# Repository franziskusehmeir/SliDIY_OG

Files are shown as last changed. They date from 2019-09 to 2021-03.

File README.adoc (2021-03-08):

== SliDIY

An affordable slider system that can be controlled with a web app via a microcontroller. It can be easily reconstructed at home with the help of a manual.

==== News
This repo has moved to https://github.com/franziskusehmeir/SliDIY

==== Authors

* *Tea Leon* - https://github.com/tealeon[TeaLeon]
* *Ehmeir Franziskus* -
https://github.com/franziskusehmeir[FranziskusEhmeir]

See also the list of
https://github.com/franziskusehmeir/SliDIY/contributors[contributors]
who participated in this project.

=== GH Page

https://franziskusehmeir.github.io/SliDIY_OG/

=== Youtrack

https://vm81.htl-leonding.ac.at/agiles/99-166/current

=== How to run

1. download & extract the latest *release.zip*

2. run the *configure.sh* 

  chmod +x script-name-here.sh
  ./configure.sh

3. enable spi on the rpi +
* *Menu* > *Preferences* > *Raspberry Pi Configuration* > *Interfaces* Tab
* set SPI to “Enabled”

4. reboot the rpi
  
5. run app

  python slidiy.py

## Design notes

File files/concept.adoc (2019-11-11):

== Concept for a motorized camera-slider

=== Introduction / Environment

A slider is a ``rail system'' that allows smooth camera movements.
Motorized versions are very expensive and non-motorized systems again
create a risk of shaky footage or irregular camera movements.

=== Starting position / current situation / analysis

==== Initial situation

The higher technical college in Leonding is a medium-sized school in the
central region of Upper Austria. One of the four departments is IT media
technology. There, media production is a clear focus of the training.

==== Current situation

In video productions, sliders have been used for many years to make
stable horizontal and vertical shots possible. These can be motorized or
not.

=== Target system / target proposals

==== Aims

The development of an affordable slider system that can be controlled
with an app via a microcontroller.

==== Target groups

People that are interested in Film, but have a very small budget.

==== Conflicting goals

Easy to use, portable system Wiring, 3D printing, fragility

=== Implementations

==== First technical realization

ESP32 + Stepper Motor + C++ Code

==== Second technical realization

ESP8266 + stepper motor + necessary hardware for connection (stepper
motor driver h-bridge) Blynk app

=== Sources

==== Lync App

https://youtu.be/dKzCZhnLUyc

==== Joystick change speed

https://youtu.be/dQuTgngoFPQ

==== Joystick Tuto

https://youtu.be/gudmACeUyVc

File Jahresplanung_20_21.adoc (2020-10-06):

== SliDIY - Jahresausblick 20/21

=== Allgemeines
Ein erschwingliches Slider-System, das mit einer Web-App über einen Microcontroller gesteuert werden kann. Es kann zu Hause mit Hilfe eines Handbuchs leicht rekonstruiert werden.

=== Status Quo
SliDIY kann einfache Bewegungen und Presets durchführen. Er benötigt aber drei Steckdosen. Es ist noch kein Case vorhanden. Verschiedene Geschwindigkeiten sind noch nicht fehlerfrei möglich. Authentifizierung läuft noch über cnc.js.

=== Meilensteine

- Hardware Änderung auf US & Usablility Verbesserungen | 01.12.20
* [ ] Ultraschallsensoren einbauen
* [ ] Kabelmanagement
** Kabel zusammenfassen
** Kabel sortieren
* [ ] Akku
** Verschiedene Möglichkeiten analysieren
** Akku/Powerbank einbauen

* [ ] Neuer Motor
* [ ] 3D Modell Case
** 3D Modell entwerfen
** 3D Modell drucken
** Case einbauen

- Software Änderung: Clean up & Features | 01.02.21
* [ ] Positionsermittlung USS
** Werte lesen vom Ultraschallsensor
** Position der Kamera berechnen mit zwei gemessenen Entfernungen

* [ ] Endabschaltung USS
** Motor aus sobald eine minimale Entfernung erreicht ist

* [ ] Code Clean Up

* [ ] Emergency Ende UI
** Stop Button in der UI hinzufügen

* [ ] Authentifizierung
** cnc.js analysieren
** grbl auth implementieren

//* [ ] Speed:Percentage

- Dokumentation & Anleitung | 01.03.21
* [ ] Genaue Domumentation
* [ ] Detaillierte Anleitung

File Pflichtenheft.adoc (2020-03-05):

== Pflichtenheft für motorisierten Kamera-Slider

_Tea Leon & Ehmeir Franziskus_

=== Ausgangssituation

Videos werden auf verschiedenen Geräten aufgenommen, mit Handys bis zu professionellen Filmkameras.

=== Ist-Situation

In semi-professionellen Filmproduktionen ist es oft wichtig, eine 
ruhige Kamerafahrt zu erstellen.

In Videoproduktionen werden seit vielen Jahren Slider verwendet um
stabile horizontale und vertikale Aufnahmen zu machen. Diese können
motorisiert sein oder nicht.

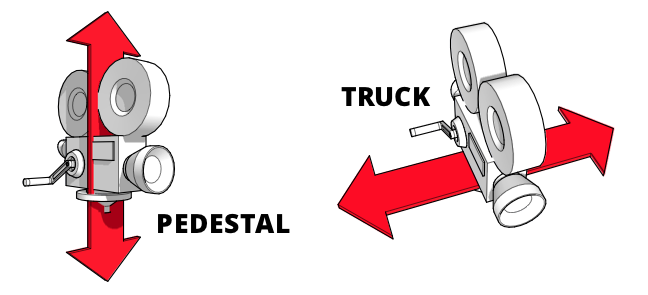
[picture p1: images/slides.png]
Movements


=== Problem

Wenn man versucht per Hand bewegte Aufnahmen zu machen, endet man meist mit verwackeltem oder sogar unbrauchbarem Videomaterial. Weiters werden die meisten Zeitrafferaufnahmen langweilig, da sie keine Bewegung beinhalten. Die Lösung dieser Probleme wären motorisierte Slidersysteme. Motorisierte Slider sind sehr teuer und meist unerschwinglich für den durchschnittlichen Anwender. Billige Alternativen sind unmotorisiert und dadurch entsteht wieder eine Verwackelungsgefahr bzw. unregelmäßige Bewegungsgeschwindigkeiten.

=== Aufgabenstellung

Es ist ein erschwingliches Slider-System zu entwickeln, das sowohl horizontale als auch schräge Kamerabewegungen durchführen kann. Die montierte Kamera wird einen vorgegeben Streckenabschnitt in einer ebenso vorgegebenen Zeit zurücklegen. Somit können z.B. auch Zeitrafferaufnahmen erstellt werden. Der Motor des Sliders wird über einen Micro-Controller angesprochen werden. Später wird das System mit einer App gesteuert werden können. Außerdem ist eine Anleitung zu erstellen, damit Leute das Slider-System nachbauen können.

=== Ziele

Filmbegeisterten Menschen soll es ermöglicht werden, mithilfe der Dokumentation selbst einen Kamera-Slider nachzubauen und ihn in Betrieb zu nehmen. Somit können sie qualitativ hochwertige Aufnahmen erstellen, die frei von Verwacklungen und Geschwindigkeitsnderungen sind.

=== User Storys nach Scrum

Als Content-Creator möchte ich reibungslose, horizontale wie auch
vertikale Kamerabewegungen anwenden.

Als Naturfotograf möchte ich bewegte Zeitraffer erstellen.

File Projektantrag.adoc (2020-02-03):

== Projektantrag

_Tea Leon & Ehmeir Franziskus_

=== Ausgangssituation

In Videoproduktionen werden seit vielen Jahren Slider verwendet um
stabile horizontale und vertikale Aufnahmen zu machen. Diese können
motorisiert sein oder nicht.

=== Problemstellung

Wenn man versucht per Hand bewegte Aufnahmen zu machen, endet man meist mit verwackeltem oder sogar unbrauchbarem Videomaterial.
Weiters werden die meisten Zeitrafferaufnahmen langweilig, da sie keine Bewegung beinhalten. Die Lösung dieser Probleme wären
motorisierte Slidersysteme. Motorisierte Slider sind sehr teuer und meist unerschwinglich für den durchschnittlichen Anwender.
Billige Alternativen sind unmotorisiert und dadurch entsteht wieder eine Verwackslungsgefahr bzw. unregelmäßige 
Bewegungsgeschwindigkeiten.

=== Aufgabenstellung

Es ist ein erschwingliches Slider-System zu entwickeln, das sowohl horizontale als auch schräge Kamerabewegungen durchführen 
kann. Die montierte Kamera wird einen vorgegeben Streckenabschnitt in einer ebenso vorgegebenen Zeit zurücklegen. 
Somit können z.B. auch Zeitrafferaufnahmen erstellt werden. Der Motor des Sliders wird über einen Micro-Controller 
angesprochen werden. Später wird das System mit einer App gesteuert werden können.

=== Anwendungsfälle

Das System ermöglicht ruhige Kamerabewegungen und bewegte Zeitrafferaufnahmen. Es eignet sich für Personen die für geringes
Geld diese Kamerabewegungen verwenden möchten. Weiters eignet es sich ach für Lehrkräfte, die ihren Schülern einen Einblick in
profesionelles Equipment geben möchten.

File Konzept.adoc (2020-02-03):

== Konzept für motorisierten Slider

_Tea Leon & Ehmeir Franziskus_

=== Einleitung / Rahmenbedingung

Ein Slider ist ein „Schienensystem“ das scheinbar schwebende
Kamerafahrten ermöglicht. Motorisierte Ausführungen sind sehr teuer und
bei unmotorisierten Systemen entsteht wieder eine Verwackslungsgefahr.

=== Ausgangslage / Ist-Situation / Analyse

==== Ausgangssituation

Die HTL Leonding ist eine mittelgroße Schule im Zentralraum OÖ. Einer der vier Ausbildungsrichtungen ist IT-Medientechnik. Dort bildet die Medienproduktion einen der Schwerpunkte der Ausbildung.

==== Ist-Situation

In Videoproduktionen werden seit vielen Jahren Slider verwendet, um
stabile horizontale und vertikale Aufnahmen zu machen. Diese können
motorisiert sein oder nicht.

=== Zielsystem / Sollvorschläge

==== Ziele

Mehr filmbegeisterten Menschen soll die Möglichkeit zum Besitz eines günstigen, motorisierten Slider-Systems geschaffen werden.
Es soll eine App zur praktischeren und bequemeren Verwendung des Systems entwickelt werden.

==== Zielgruppen

Filminteressierte Personen mit sehr kleinem Budget.
Lehrkräfte, die ihren Schülern professionelles Equipment zeigen möchten.
Fotografen, die bewegte Zeitrafferaufnahmen erstellen möchten. 

==== Zielkonflikte

Leicht anwendbares, portables System 
Verkabelungen, 3D Druck, Zerbrechlichkeit

=== Realisierung

Arduino UNO + CNC Shield + Stepper Motor

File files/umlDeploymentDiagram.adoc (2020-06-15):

@startuml

skinparam ArrowColor black
skinparam handwritten true
skinparam borderColor black
skinparam backgroundColor transparent
skinparam nodeShadowing false
skinparam nodeBackgroundColor transparent
skinparam artifactShadowing false
skinparam artifactBackgroundColor transparent
skinparam componentShadowing false
skinparam componentBackgroundColor transparent
skinparam componentBorderColor black

@startuml

node raspberryPi{
 artifact nodejsApp{
    artifact UI
    artifact Logic
 }
}

node arduino{
 artifact grbl
 component CNCShield
}

node steppermotor{

}

Logic == grbl : <<serial>>
CNCShield == steppermotor : <<i2c>>

@enduml
@enduml

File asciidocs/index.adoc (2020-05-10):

= SliDIY

== Pflichtenheft "Was mache ich"

=== Ausgangssituation

Videos werden auf verschiedenen Geräten aufgenommen, mit Handys bis zu professionellen Filmkameras.

=== Ist-Situation

In semi-professionellen Filmproduktionen ist es oft wichtig, eine 
ruhige Kamerafahrt zu erstellen.

In Videoproduktionen werden seit vielen Jahren Slider verwendet um
stabile horizontale und vertikale Aufnahmen zu machen. Diese können
motorisiert sein oder nicht.

Movements

=== Problemstellung

Wenn man versucht per Hand bewegte Aufnahmen zu machen, endet man meist mit verwackeltem oder sogar unbrauchbarem Videomaterial. Weiters werden die meisten Zeitrafferaufnahmen langweilig, da sie keine Bewegung beinhalten. Die Lösung dieser Probleme wären motorisierte Slidersysteme. Motorisierte Slider sind sehr teuer und meist unerschwinglich für den durchschnittlichen Anwender. Billige Alternativen sind unmotorisiert und dadurch entsteht wieder eine Verwackelungsgefahr bzw. unregelmäßige Bewegungsgeschwindigkeiten.

=== Aufgabenstellung

Es ist ein erschwingliches Slider-System zu entwickeln, das sowohl horizontale als auch schräge Kamerabewegungen durchführen kann. Die montierte Kamera wird einen vorgegeben Streckenabschnitt in einer ebenso vorgegebenen Zeit zurücklegen. Somit können z.B. auch Zeitrafferaufnahmen erstellt werden. Der Motor des Sliders wird über einen Micro-Controller angesprochen werden. Später wird das System mit einer App gesteuert werden können. Außerdem ist eine Anleitung zu erstellen, damit Leute das Slider-System nachbauen können.

==== Funktionale Anforderungen

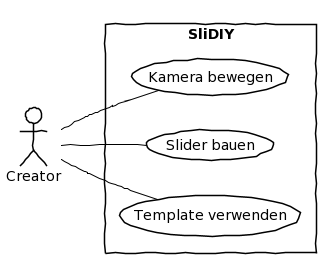
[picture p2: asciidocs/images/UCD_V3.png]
usecasediagram


==== Nichtfunktionale Anforderungen

Die Oberfläche gewährleistet eine gute Übersicht und eine leichte Bedienung. +
Die Komponenten des Systems sind erschwinglich. +
Es wird eine simple Anleitung zum Nachbau zur Verfügung gestellt.

=== Ziele

Filmbegeisterten Menschen soll es ermöglicht werden, mithilfe der Dokumentation selbst einen Kamera-Slider nachzubauen und ihn in Betrieb zu nehmen. Somit können sie qualitativ hochwertige Aufnahmen erstellen, die frei von Verwacklungen und Geschwindigkeitsnderungen sind.

=== User Storys nach Scrum

Als Content-Creator möchte ich reibungslose, horizontale wie auch
vertikale Kamerabewegungen anwenden.

Als Naturfotograf möchte ich bewegte Zeitraffer erstellen.

== Entwurf "Wie mache ich es"

=== System Architecture (Hardware)

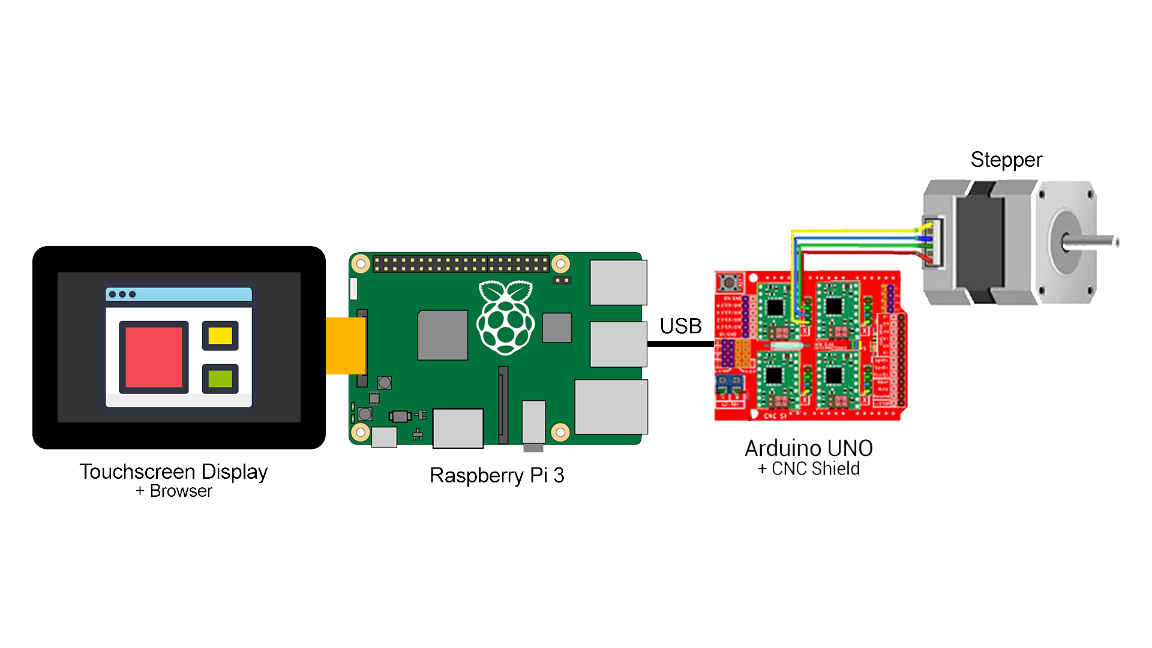
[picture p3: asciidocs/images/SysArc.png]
systemarchitecture


=== Deployment Diagram

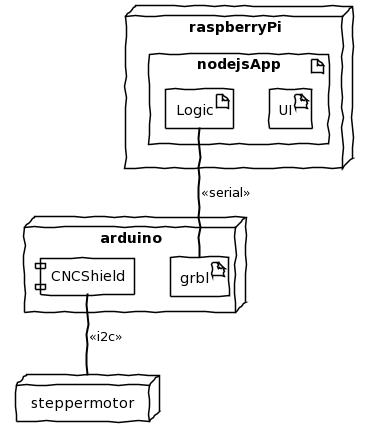
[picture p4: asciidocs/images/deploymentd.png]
deployment_diagram


=== Use Case Diagram

usecasediagram

=== Youtrack Diagram Epic

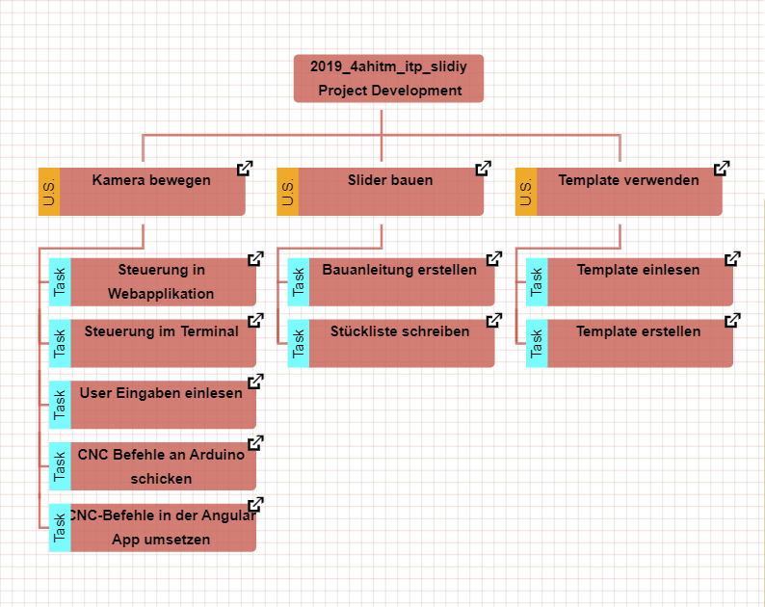
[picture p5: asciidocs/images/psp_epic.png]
pspepic


=== Youtrack Diagram Sprints
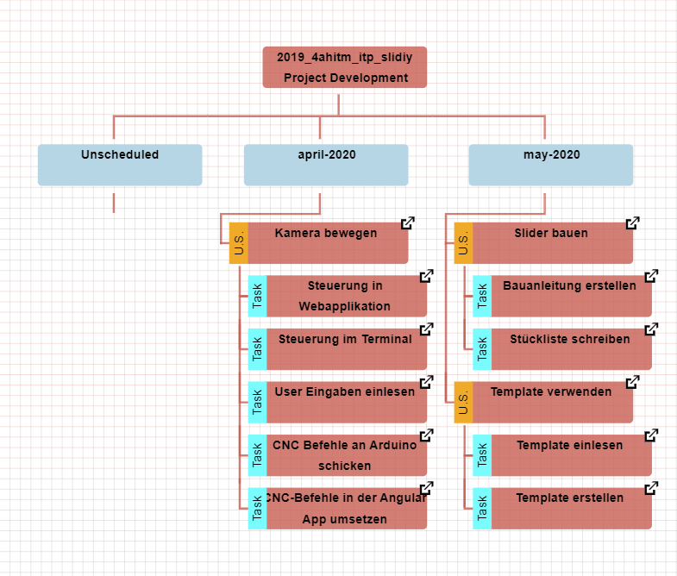
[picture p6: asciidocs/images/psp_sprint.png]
pspsprints


== Projekthandbuch "Organisatorische Rahmenbedigungen"

=== Gantt Diagram
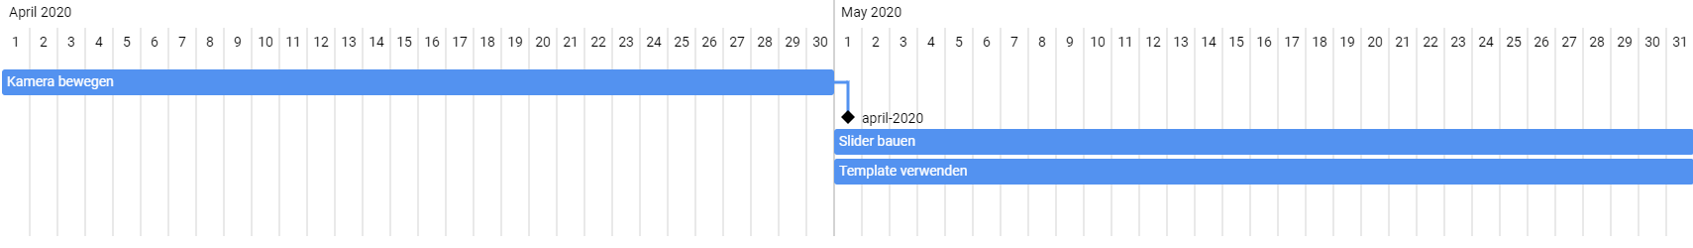
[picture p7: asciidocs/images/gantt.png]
gantt


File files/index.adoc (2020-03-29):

== Pflichtenheft "Was mache ich"

=== Ausgangssituation

Videos werden auf verschiedenen Geräten aufgenommen, mit Handys bis zu professionellen Filmkameras.

=== Ist-Situation

In semi-professionellen Filmproduktionen ist es oft wichtig, eine 
ruhige Kamerafahrt zu erstellen.

In Videoproduktionen werden seit vielen Jahren Slider verwendet um
stabile horizontale und vertikale Aufnahmen zu machen. Diese können
motorisiert sein oder nicht.

Movements

=== Problemstellung

Wenn man versucht per Hand bewegte Aufnahmen zu machen, endet man meist mit verwackeltem oder sogar unbrauchbarem Videomaterial. Weiters werden die meisten Zeitrafferaufnahmen langweilig, da sie keine Bewegung beinhalten. Die Lösung dieser Probleme wären motorisierte Slidersysteme. Motorisierte Slider sind sehr teuer und meist unerschwinglich für den durchschnittlichen Anwender. Billige Alternativen sind unmotorisiert und dadurch entsteht wieder eine Verwackelungsgefahr bzw. unregelmäßige Bewegungsgeschwindigkeiten.

=== Aufgabenstellung

Es ist ein erschwingliches Slider-System zu entwickeln, das sowohl horizontale als auch schräge Kamerabewegungen durchführen kann. Die montierte Kamera wird einen vorgegeben Streckenabschnitt in einer ebenso vorgegebenen Zeit zurücklegen. Somit können z.B. auch Zeitrafferaufnahmen erstellt werden. Der Motor des Sliders wird über einen Micro-Controller angesprochen werden. Später wird das System mit einer App gesteuert werden können. Außerdem ist eine Anleitung zu erstellen, damit Leute das Slider-System nachbauen können.

==== Funktionale Anforderungen

usecasediagram

==== Nichtfunktionale Anforderungen

Die Oberfläche gewährleistet eine gute Übersicht und eine leichte Bedienung. +
Die Komponenten des Systems sind erschwinglich. +
Es wird eine simple Anleitung zum Nachbau zur Verfügung gestellt.

=== Ziele

Filmbegeisterten Menschen soll es ermöglicht werden, mithilfe der Dokumentation selbst einen Kamera-Slider nachzubauen und ihn in Betrieb zu nehmen. Somit können sie qualitativ hochwertige Aufnahmen erstellen, die frei von Verwacklungen und Geschwindigkeitsnderungen sind.

=== User Storys nach Scrum

Als Content-Creator möchte ich reibungslose, horizontale wie auch
vertikale Kamerabewegungen anwenden.

Als Naturfotograf möchte ich bewegte Zeitraffer erstellen.

== Entwurf "Wie mache ich es"

=== System Architecture (Hardware)

systemarchitecture

=== Deployment Diagram

deployment_diagram

=== Use Case Diagram

usecasediagram

=== Youtrack Diagram Epic

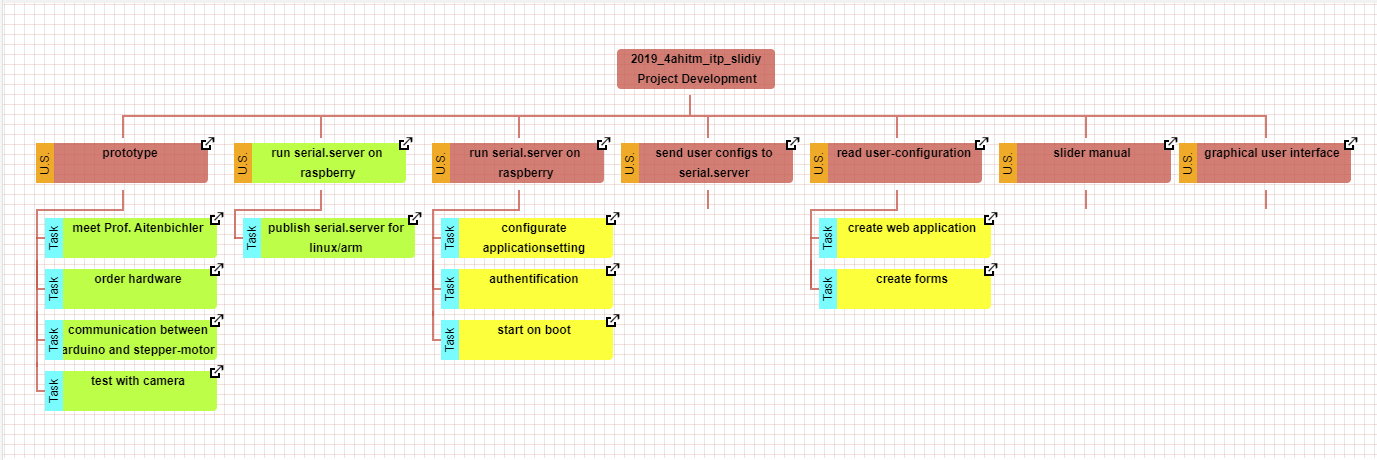
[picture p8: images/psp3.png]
pspepic


=== Youtrack Diagram Sprints
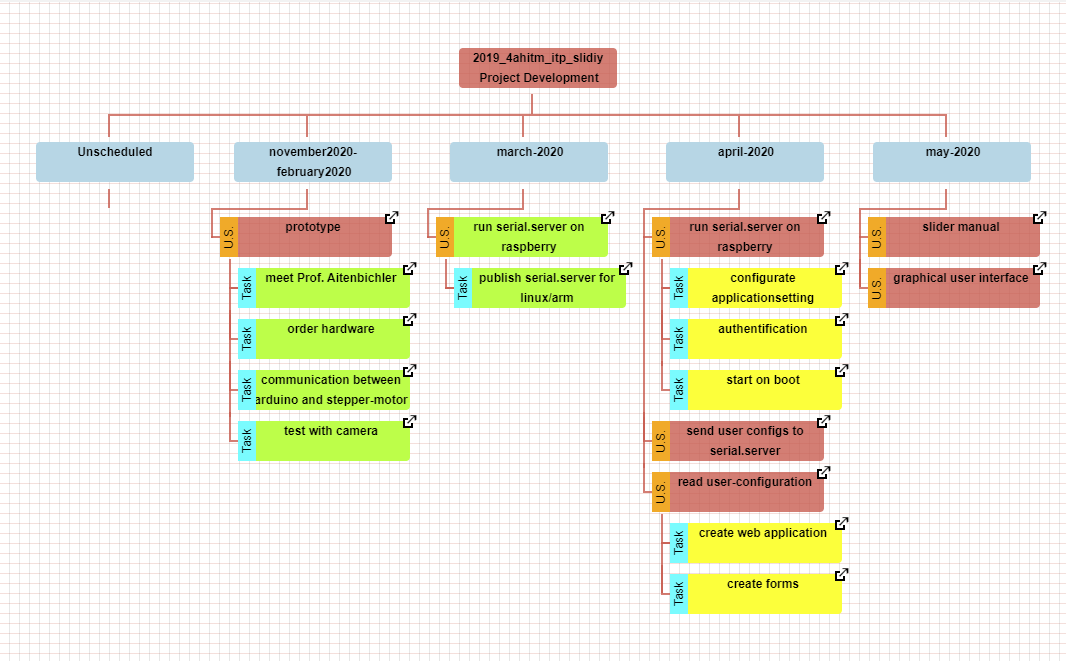
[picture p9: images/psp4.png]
pspsprints


== Projekthandbuch "Organisatorische Rahmenbedigungen"

=== Gantt
gantt

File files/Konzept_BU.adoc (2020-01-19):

== Konzept für motorisierten Slider

=== Einleitung / Rahmenbedingung

Ein Slider ist ein „Schienensystem“ das scheinbar schwebende
Kamerafahrten ermöglicht. Motorisierte Ausführungen sind sehr teuer und
bei unmotorisierten Systemen entsteht wieder eine Verwackslungsgefahr.

=== Ausgangslage / Ist-Situation / Analyse

==== Ausgangssituation

Die HTL Leonding ist eine mittelgroße Schule im Zentralraum OÖ. Einer
der vier Ausbildungsrichtungen ist IT-Medientechnik. Dort bildet die
Medienproduktion einen klaren Schwerpunkt der Ausbildung.

==== Ist-Situation

In Videoproduktionen werden seit vielen Jahren Slider verwendet, um
stabile horizontale und vertikale Aufnahmen zu machen. Diese können
motorisiert sein oder nicht.

=== Zielsystem / Sollvorschläge

==== Ziele

Es ist ein erschwingliches Slider-System zu entwickeln, dass über einen
Micro-Controller mit einer App gesteuert werden kann.

==== Zielgruppen

Filminteressierte Personen mit sehr kleinem Budget.

==== Zielkonflikte

Leicht anwendbares, portables System Verkabelungen, 3D Druck,
Zerbrechlichkeit

=== Realisierungen

==== Realisierung 1

ESP8266 + Stepper Motor + Nötige Hardware zur Verbindung (stepper motor
driver h-bridge) Blynk-App

==== Realisierung 2

ESP32 + Stepper Motor + C++ Code

=== Qellen

==== Lync App

https://youtu.be/dKzCZhnLUyc

==== Joystick change speed

https://youtu.be/dQuTgngoFPQ

==== Joystick Tuto

https://youtu.be/gudmACeUyVc

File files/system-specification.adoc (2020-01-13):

== Pflichtenheft für motorisierten Kamera-Slider

_Ehmeir Franziskus & Tea Leon_

=== Ausgangssituation

Die HTL Leonding ist eine mittelgroße Schule im Zentralraum OÖ. Einer der vier Ausbildungsrichtungen ist IT-Medientechnik. Dort bildet die Medienproduktion einen klaren Schwerpunkt der Ausbildung.

=== Ist-Situation

Horizontale und vertikale Videoaufnahmen sind händisch oft verwackelt. Um stabile Aufnahmen zu erreichen werden teure Werkzeuge benötigt.

Movements

=== Problem

Motorisierte Slider sind sehr teuer und meist unerschwinglich für den durchschnittlichen Anwender. Billige Alternativen sind unmotorisiert und dadurch entsteht wieder eine Verwackslungsgefahr bzw. unregelmäßige Bewegungsgeschwindigkeiten.

=== Aufgabenstellung
Es ist ein erschwingliches Slider-System zu entwickeln, dass über einen Micro-Controller mit einer App gesteuert werden kann.

=== Ziele

Mehr filmbegeisterten Menschen soll die Möglichkeit zum Besitz eines günstigen, motorisierten Slider-Systems geschaffen werden.

=== User Storys nach Scrum

* Als Content-Creator möchte ich reibungslose, horizontale wie auch vertikale Kamerabewegungen anwenden.
* Als Naturfotograf möchte ich bewegte Zeitraffer erstellen.
* Als Lehrer möchte ich meinen Schülern die Möglichkeit bieten mit professionellem Equipment zu arbeiten.

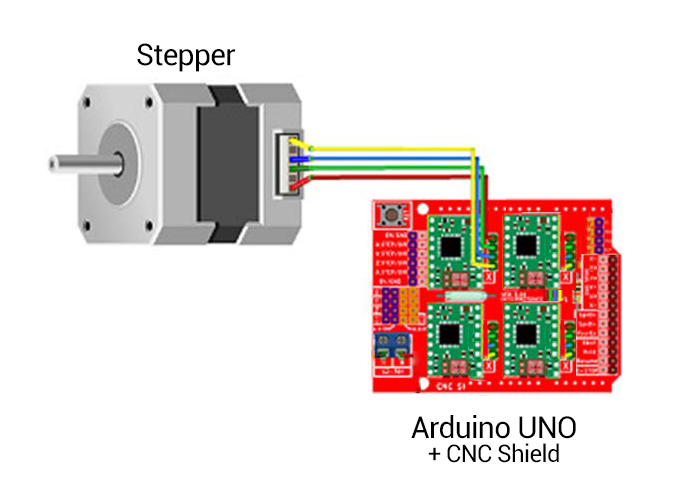
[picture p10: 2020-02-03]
docs/images/systemarchitecture.jpg

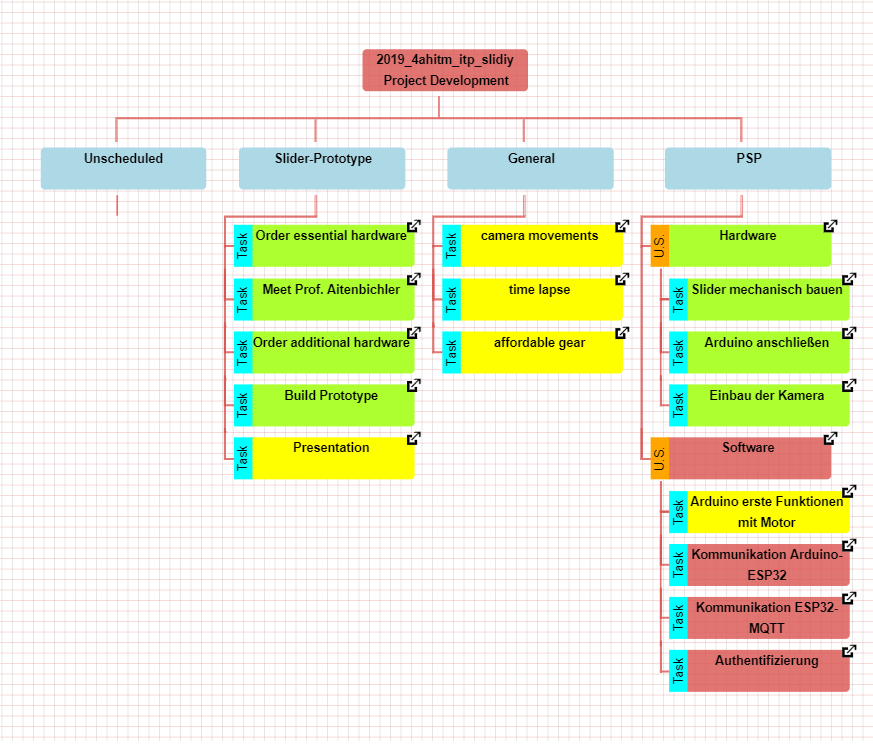
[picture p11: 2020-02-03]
docs/images/psp.PNG

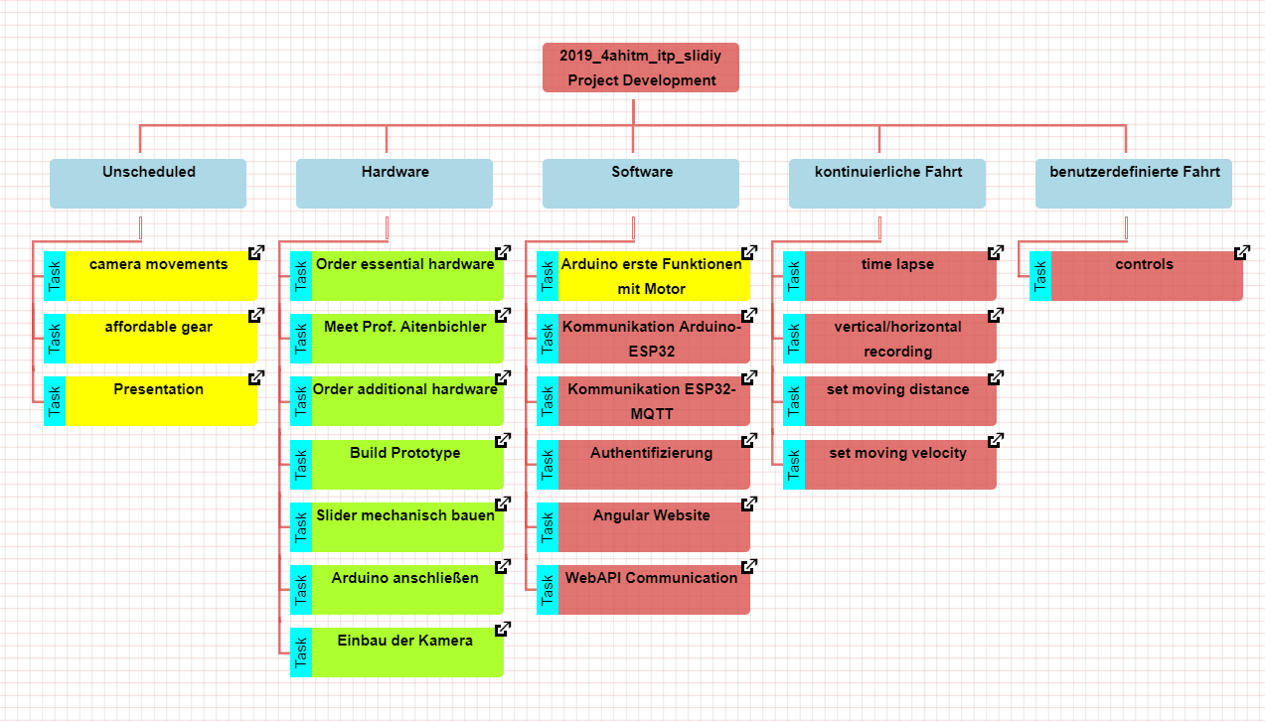
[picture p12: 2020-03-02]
docs/images/psp_new.PNG

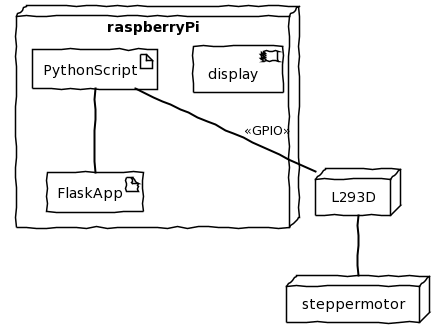
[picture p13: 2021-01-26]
docs/images/deploymentd.png

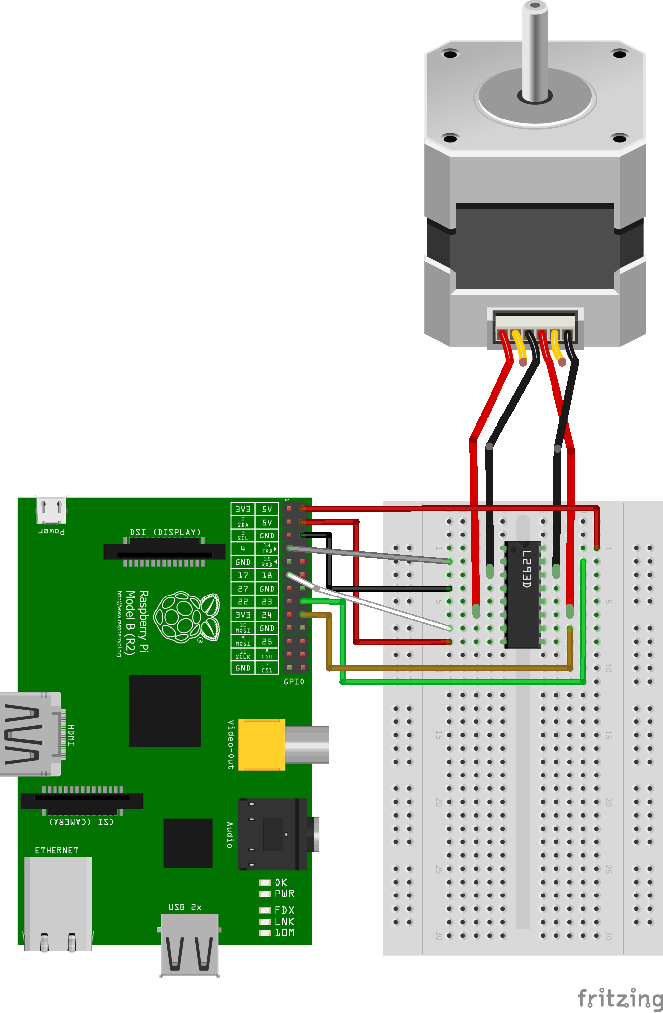
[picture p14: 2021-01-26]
docs/images/SysArcNew.png

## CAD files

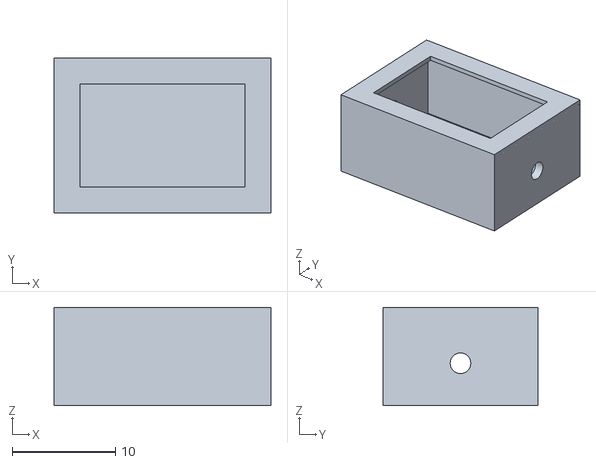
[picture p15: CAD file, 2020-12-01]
files/3d_case.stl
21.0 x 15.0 x 9.50

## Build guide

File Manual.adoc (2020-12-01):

= How to build a motorized slider
Doc Writer <doc.writer@asciidoctor.org>
v0.1.0, 2020-08-01
:toc: left

== Build your own slider

With the help of SliDIY it is made possible to easily build your own motorized slider.
SliDIY is a web application which controls the movement of your slider.

Aufbau

=== Hardware list

camera-slider: +
https://www.amazon.de/gp/product/B06Y46H989/

stepper motor: +
https://www.amazon.de/gp/product/B00PNEQKC0/

Arduino Uno with CNC-Shield V3.0 (with USB-cable and drivers) +

touchscreen display (optional): +
https://www.amazon.de/Raspberry-Pi-7-Inch-Screen-Display/dp/B014WKCFR4 +

timing belt with accessories: +
https://www.amazon.de/gp/product/B07JGXG7S2/ref=ppx_yo_dt_b_asin_title_o00_s00?ie=UTF8&psc=1

=== Software installation

Download the Raspbian Buster Lite Image: +
https://www.raspberrypi.org/downloads/raspbian/

write the image with help of the Raspberry Pi Imager onto the sd-card: +
https://www.raspberrypi.org/downloads/

first follow the instruction of the Raspberry Pi

then unlock ssh in the raspi-config

``raspi-config`` +
In this menu change to the tab "Interfacing Options" and enable the option "SSH". After this you need to reboot your
your Raspberry Pi.

install CNCJS on the Raspberry: +

``
sudo apt-get update
``

``
sudo apt-get upgrade -y
``

``
sudo apt-get dist-upgrade -y
``

``
sudo apt-get install -y build-essential git
``

``
sudo apt-get install -y htop iotop nmon lsof screen
``

``
sudo reboot
``

``
curl -sL https://deb.nodesource.com/setup_8.x | sudo -E bash -
``

``
sudo apt install -y nodejs build-essential
``

``
sudo apt-get install -y npm
``

``
sudo npm install -g npm@latest
``

``
sudo npm install -g cncjs@latest --unsafe-perm
``

``
cncjs
``

you can now check under localhost:8000 if the installation was successful

reboot Raspberry Pi  +
``
sudo reboot
``

=== 3D-Case

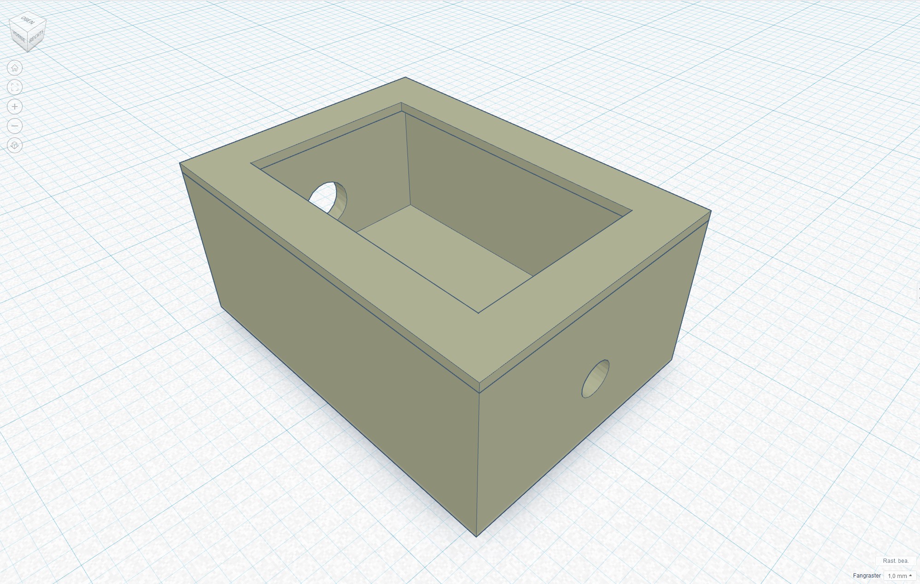
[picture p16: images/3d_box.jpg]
3d-case


We used https://www.tinkercad.com/[Tinkercad] for modeling our 3D-Case since it is made for people who have
never touched a 3D-modeling software like Blender or Cinema4D. Tinkercad is a simple web-based modeling-tool.
You have to export your 3d-model as a STL-file for the 3d-printing.

other option to Tinkercad:

* Blender
* Cinema4D
* Meshlab
* Meshmixer
* Microsoft 3D Builder

There are no strict rules on how to design your case, so model it the way you want or download our model!

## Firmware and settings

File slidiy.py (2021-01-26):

from flask import Flask, render_template_string, request 
import RPi.GPIO as GPIO
import time
 
GPIO.setmode(GPIO.BCM)
GPIO.setwarnings(False)
coil_A_2_pin = 4 # A\ gruen-weiss
coil_B_1_pin = 17 # B rot-lila
coil_A_1_pin = 23 # A schwarz-schwarz
coil_B_2_pin = 24 # B\ blau-grau

# anpassen, falls andere Sequenz
# eine ganze Sequenz entspricht 0.08cm
StepCount = 4
Seq = list(range(0, StepCount))
Seq[0] = [1,0,1,0]
Seq[1] = [0,1,1,0]
Seq[2] = [0,1,0,1]
Seq[3] = [1,0,0,1]

GPIO.setup(coil_A_1_pin, GPIO.OUT)
GPIO.setup(coil_A_2_pin, GPIO.OUT)
GPIO.setup(coil_B_1_pin, GPIO.OUT)
GPIO.setup(coil_B_2_pin, GPIO.OUT)

# Slider-Laenge in cm
sliderLength = 55

# Anzahl an Steps fuer eine ganze Kamerafahrt
completeSteps = sliderLength/0.08

app = Flask(__name__)
 
#HTML 

TPL = '''

<html>

    <head>
        <title>SliDIY</title>
        <link rel="stylesheet" href="{{ url_for('static', filename='styles/style.css') }}">
        
    </head>

    <body>

    <div>

    <h2>SliDIY</h2>

        <form method="POST" action="run">
            
            <p>Distance: <span id="value"></span>cm</p>
            <input type="range" id="distance" name="distance" min="-55" max="55" value="0"><br>
            
            <label for="time">Time in s:</label><br>
            <input type="number" id="time" name="time" min=1 value=5><br>
            
            <br>
            <input type="submit" value="run" />

        </form>
    </div>
    
        <script>
            var slider = document.getElementById("distance");
            var output = document.getElementById("value");

            output.innerHTML = slider.value;

            slider.oninput = function() {
                output.innerHTML = this.value;
            }
        </script>
        
    </body>

</html>

'''

# Zustand der Pins setzen
def setStep(w1, w2, w3, w4):
    GPIO.output(coil_A_1_pin, w1)
    GPIO.output(coil_A_2_pin, w2)
    GPIO.output(coil_B_1_pin, w3)
    GPIO.output(coil_B_2_pin, w4)
 
def acceleration(delay, steps, currentStep):
    acc_time=0.01-delay
    acc_steps=steps/9
    acc_delay=acc_time/acc_steps
    if(delay<0.01 and currentStep < acc_steps):
        time.sleep(delay+(acc_delay*(acc_steps-currentStep)))
    elif(delay<0.01 and currentStep > steps-acc_steps):
        time.sleep(delay+(acc_delay*(acc_steps-(steps-currentStep))))
    else:
        time.sleep(delay)
        
    
 
def forward(delay, steps):
    for i in range(steps):
        for j in range(StepCount):
            setStep(Seq[j][0], Seq[j][1], Seq[j][2], Seq[j][3])
            acceleration(delay, steps, i)
 
def backwards(delay, steps):
    for i in range(steps):
        for j in reversed(range(StepCount)):
            setStep(Seq[j][0], Seq[j][1], Seq[j][2], Seq[j][3])
            acceleration(delay, steps, i)
            
 

@app.route("/")

def home():

    setStep(0,0,0,0)

    return render_template_string(TPL)
 

@app.route("/run", methods=["POST"])

def run():

    setStep(0,0,0,0)

    # Get slider Values
    distance = request.form["distance"]
    
    time = int(request.form["time"])
    
    print(int(distance))

    if(int(distance) > sliderLength):
        distance=0
        
    steps = int(distance)/0.08
    
    delay = 0
    
    # /4 damit die richtige Zeit rauskommt
    if(steps != 0):
        delay = time/steps/4
    
    if(delay < 0):
        delay = -delay
    
    if(delay<0.003):
        delay = 0.003

    print(delay)

    print(int(steps))

    if(float(steps) > 0):
        forward(delay, int(steps))
        print("rotate anti-clockwise")
        
    if(float(steps) < 0):
        backwards(delay, int(steps)*(-1))
        print("rotate clockwise")
        
    setStep(0,0,0,0)
    

    return render_template_string(TPL)

 

# Run the app on the local development server

if __name__ == "__main__":

    app.run()

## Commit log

2020-02-02 add use case diagram
2020-02-02 add use case diagram to README.adoc
2020-12-01 add 3d-case to manual
    [3d_case.stl]
2021-01-17 add standby-phase to stepper
2021-01-17 updated stepper sequence
2021-01-18 limit max velocity
